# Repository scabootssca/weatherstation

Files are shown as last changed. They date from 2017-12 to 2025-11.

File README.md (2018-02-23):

Needs Src/shared/config.h made with this format:

# config.h
```
#ifndef _CONFIG_H_
#define _CONFIG_H_

#define SERVER_IP_ADDRESS "XXX.XXX.XXX.XXX"
#define SERVER_PORT 80
#define MY_IP XXX, XXX, XXX, XXX
#define GATEWAY_IP XXX, XXX, XXX, XXX
#define SUBNET_MASK XXX, XXX, XXX, XXX
#define WIFI_SSID "XXXXXXXXXXX"
#define WIFI_PASS "*******************"
#define GMT_OFFSET XX (-X or just X in hours)
#define ESP_ATMEGA_BAUD_RATE 4800

#endif
```

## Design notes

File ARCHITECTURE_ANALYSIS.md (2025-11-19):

# ATmega Weather Logger - Architecture Analysis

## Executive Summary

This document provides a comprehensive technical analysis of the ATmega Weather Logger codebase for its intended use as a budget-friendly PLC-esque automation system for greenhouses, climate automation, and gardens.

---

## 1. System Architecture Overview

### Dual-Processor Design
```
[Sensors] --> [ATmega328p] --> [SoftwareSerial @ 4800 baud] --> [ESP8266] --> [WiFi] --> [Server]
```

| Component | Role | Communication |
|---|---|---|
| ATmega328p | Main controller - sensor reading, data processing, storage | I2C, SPI, SoftwareSerial |
| ESP8266 | WiFi module - HTTP requests to server | SoftwareSerial, WiFi |

### Hardware Components

**Sensors:**
- BME280 (I2C @ 0x76) - Temperature, Humidity, Barometric Pressure
- BH1750 (I2C @ 0x23) - Lux/Light level
- DS1307 (I2C @ 0x68) - Real-time clock
- Wind vane - Analog input (ADC)
- Anemometer - Digital interrupt (pulse counting)
- Rain gauge - Digital interrupt (tipping bucket)
- Battery voltage - Analog input with voltage divider

**Peripheral ICs:**
- MCP23008 (I2C @ 0x20) - GPIO expander for ESP control
- 23A1024 (SPI) - External 1Mbit SRAM for data storage

---

## 2. Major Sections and Key Functions Analysis

### 2.1 Main Controller (`ATmega328p.ino`)

#### Initialization (`setup()`)
**Location:** Lines 328-536

**Purpose:** System initialization including watchdog, peripherals, and state restoration.

**Key Operations:**
- Enables 8-second watchdog timer
- Initializes I2C bus with timeout and recovery
- Configures SPI for external SRAM
- Sets up GPIO expander (MCP23008) for ESP control
- Configures interrupts for anemometer and rain gauge
- Restores state from external SRAM or initializes fresh
- Sends boot debug message to server

#### Main Loop (`loop()`)
**Location:** Lines 743-790

**Purpose:** Core processing loop with periodic sampling and reading generation.

**Key Operations:**
1. Pet watchdog timer
2. Handle ESP state machine
3. Take samples every 2 seconds
4. Create weather readings every 5 minutes (150 samples)
5. Trigger submission every 20 minutes (4 readings)

#### ESP State Machine (`handle_esp()`)
**Location:** Lines 539-630

**Purpose:** Manages ESP8266 lifecycle for reliable communication.

**States:**
| State | Description |
|---|---|
| `ESP_STATE_SLEEP` | ESP in deep sleep, no power consumption |
| `ESP_STATE_RESETTING` | ESP being reset, waiting for ready signals |
| `ESP_STATE_IDLE` | ESP awake and ready for commands |
| `ESP_STATE_AWAITING_RESULT` | Request sent, waiting for response |
| `ESP_STATE_AWAITING_DEBUG_RESULT` | Debug request sent |

#### Anemometer ISR (`anemometerISR()`)
**Location:** Lines 219-258

**Purpose:** Interrupt-driven wind speed measurement with debouncing.

**Key Features:**
- 50ms debounce (max ~58.4 MPH measurable)
- Accumulates time deltas for averaging
- Tracks minimum delta for gust detection
- Handles millis() rollover

#### Data Sampling (`take_sample()`)
**Location:** Lines 1182-1258

**Purpose:** Collects all sensor data and accumulates for averaging.

**Sampled Data:**
- Battery voltage (every 25th sample)
- Wind speed and direction
- Rain bucket pulses
- Temperature, pressure, humidity (BME280)
- Light level (BH1750)

### 2.2 Data Storage Module (`MCP_23A1024.h`)

#### Memory Layout
```
[0-4]     BLANK
[5-9]     populated key (0xFAD00BA6)
[10-12]   readIndex
[13-19]   BLANK
[20-22]   writeIndex
[23-31]   BLANK
[32-end]  readingAccumulator + readings circular buffer
```

**Maximum Readings:** Calculated as `(131072 - SRAM_ADDR_READINGS) / sizeof(WeatherReading)`

#### Key Functions

| Function | Purpose |
|---|---|
| `sram_init()` | Initialize SPI settings, set sequential mode |
| `sram_get_populated()` | Check/set magic key for data persistence |
| `sram_read_accumulator()` / `sram_write_accumulator()` | Persist accumulator state |
| `sram_read_reading()` / `sram_write_reading()` | Read/write from circular buffer |

### 2.3 Weather Data Module (`weather_readings.h`)

#### Data Structures

**WeatherReading** - Final averaged reading (40 bytes):
```c
struct WeatherReading {
    uint32_t timestamp;
    float temperature, humidity, pressure;
    float batteryMv, windGust, windSpeed, windDirection, lux;
    uint32_t rain;
};
```

**WeatherReadingAccumulator** - Sample accumulation (58 bytes):
```c
struct WeatherReadingAccumulator {
    uint32_t timestamp;
    int32_t temperature;
    uint32_t humidity, batteryMv, windGust, windSpeed, rain;
    uint64_t pressure, lux;
    float windDirectionX, windDirectionY;  // For vector averaging
    uint8_t numSamples, numBatterySamples;
};
```

#### Vector Wind Direction Averaging (`store_accumulator()`)
**Location:** Lines 109-166

Uses Cartesian coordinate averaging to properly handle circular mean:
```c
float avgWindX = src.windDirectionX / float(src.numSamples);
float avgWindY = src.windDirectionY / float(src.numSamples);
float angleRadians = atan(avgWindY / avgWindX);
// Quadrant correction for full 360 degrees
```

### 2.4 WiFi Module (`ESP8266.ino`)

#### Serial Protocol
**Format:** `[Command Byte][Length Byte][Data...]`

**Commands:**
| Code | Command | Action |
|---|---|---|
| 0 | PING | Echo test |
| 1 | REQUEST | Send HTTP GET |
| 2 | SLEEP | Enter deep sleep |
| 6 | IDLE | Reset result pins |

#### HTTP Communication (`send_request()`)
**Location:** Lines 294-358

- Connects to configured WiFi
- Sends HTTP GET request with weather data as URL parameters
- Parses response for "Success" keyword
- Sets GPIO pins to signal result to ATmega

---

## 3. Potential Bugs and Issues

### 3.1 Critical Bugs

#### Bug 1: Integer Overflow in Wind Speed Accumulation
**Location:** `ATmega328p.ino:1049`
```c
sampleAccumulator.windSpeed += int32_t(anemometerMph*100);
```
**Issue:** With 150 samples at high wind speeds, this can overflow. At 50 MPH average:
`150 * 50 * 100 = 750,000` (safe for int32_t, but marginal)

**Risk:** Medium - Only affects sustained high winds

#### Bug 2: Division by Zero in Wind Direction
**Location:** `weather_readings.h:138`
```c
float angleRadians = atan(avgWindY/avgWindX);
```
**Issue:** If `avgWindX == 0`, this causes undefined behavior.

**Fix Required:** Add check for `avgWindX == 0` before division.

#### Bug 3: Race Condition in Anemometer Variables
**Location:** `ATmega328p.ino:1036-1038`
```c
cli();
float averagePulseTDelta = anemometerTDeltaAccumulator / float(anemometerPulses);
anemometerPulses = 0;
anemometerTDeltaAccumulator = 0;
sei();
```
**Issue:** `anemometerTDeltaAccumulator` is `uint64_t` which requires multiple instructions to read on 8-bit AVR. While `cli()` is called, the ISR could have updated it atomically during the division if the division is optimized.

**Risk:** Low - The `cli()` prevents the issue, but code is fragile.

#### Bug 4: Buffer Overflow in ESP Serial
**Location:** `ESP8266.ino:243-246`
```c
if (ATmegaSerialIndex >= ATMEGA_BUFFER_SIZE-1) {
    Serial.println("Serial buffer overflow!");
    ATmegaSerialIndex = 0;
}
```
**Issue:** This check happens AFTER writing to the buffer, potentially allowing one byte overflow.

#### Bug 5: Uninitialized lastAnemometerPulseMillis After Reset
**Location:** `ATmega328p.ino:221-225`
```c
if (lastAnemometerPulseMillis == 0) {
    lastAnemometerPulseMillis = millis();
    return;
}
```
**Issue:** If the first pulse happens at millis() = 0 (just after reset), it will be skipped and the next tDelta will be very large.

### 3.2 Security Vulnerabilities

#### Vulnerability 1: No HTTPS - Data in Plaintext
**Location:** `ESP8266.ino:320-322`
```c
client.print(String("GET ") + url + " HTTP/1.1\r\n" + ...);
```
**Risk:** HIGH - All sensor data transmitted unencrypted
**Impact:** Data interception, potential for injection attacks

#### Vulnerability 2: Hardcoded Credentials in Config
**Location:** `config.h` (user-created)
```c
#define WIFI_PASS "*******************"
```
**Risk:** Medium - Credentials stored in plaintext
**Mitigation:** File is gitignored, but should use secure storage

#### Vulnerability 3: No Server Authentication
**Issue:** Server response is only checked for "Success" string - no verification of server identity
**Risk:** Medium - Man-in-the-middle attacks possible

#### Vulnerability 4: URL Injection Potential
**Location:** `ATmega328p.ino:814-865`
**Issue:** Sensor values are concatenated directly into URL without sanitization
**Risk:** Low - Controlled input from sensors, but no validation

### 3.3 Performance Bottlenecks

#### Bottleneck 1: String Concatenation in URL Generation
**Location:** `ATmega328p.ino:814-865`
```c
String outputUrl = "/report.php?";
outputUrl += "temp=";
outputUrl += weatherReading.temperature;
// ... repeated 15+ times
```
**Issue:** Each `+=` causes memory reallocation, fragmenting heap
**Impact:** ~300+ bytes allocated/deallocated per submission

#### Bottleneck 2: Blocking Delays in Battery Reading
**Location:** `ATmega328p.ino:1119-1141`
```c
mcp.digitalWrite(MCP_SOLAR_ENABLE_PIN, LOW);
delay(50);
mcp.digitalWrite(MCP_BAT_DIV_ENABLE_PIN, HIGH);
delay(50);
```
**Issue:** 100ms+ blocking delay during every 25th sample
**Impact:** Missed anemometer pulses during battery reading

#### Bottleneck 3: Slow SoftwareSerial Baud Rate
**Location:** `config.h`
```c
#define ESP_ATMEGA_BAUD_RATE 4800
```
**Issue:** At 4800 baud, a 200-byte URL takes ~400ms to transmit
**Impact:** Extended communication time, increased power consumption

#### Bottleneck 4: pow() Function for ADC Oversampling
**Location:** `ATmega328p.ino:731`
```c
short numSamples = (int)pow(4.0, oversampleBits);
```
**Issue:** Floating-point pow() is expensive; result is always 16 (4^2)
**Fix:** Use `(1 << (2 * oversampleBits))` or pre-computed constant

---

## 4. Code Quality Evaluation

### 4.1 Readability

**Score: 6/10**

**Strengths:**
- Consistent naming convention (snake_case for functions, camelCase for variables)
- Good use of `#define` for configuration constants
- Helpful comments explaining WMO standards compliance
- Clear separation of concerns between files

**Weaknesses:**
- Many commented-out code blocks (e.g., lines 667-707, 709-720)
- Magic numbers in some places (e.g., 50ms debounce, line 240)
- Long functions (setup() is 200+ lines)
- Inconsistent debug print formatting

### 4.2 Maintainability

**Score: 5/10**

**Strengths:**
- Modular design with separate header files
- Configuration centralized in config.h
- Debug levels (0-3) for different verbosity

**Weaknesses:**
- No unit tests
- Functions in header files (`weather_readings.h`, `MCP_23A1024.h`) - should be .cpp
- Global state makes testing difficult
- No API documentation
- Hardcoded I2C addresses scattered throughout

### 4.3 Best Practices Adherence

**Score: 6/10**

**Adherence:**
- Watchdog timer implementation
- Power management (forced mode, deep sleep)
- State persistence across resets
- Vector averaging for circular data

**Violations:**
- Functions defined in headers (not inline)
- No const correctness on function parameters
- Raw pointers without bounds checking
- No PROGMEM usage for constant strings
- Large String objects on stack

---

## 5. Improvement Recommendations

### 5.1 Critical Fixes

1. **Fix division by zero in wind direction calculation**
   ```c
   if (avgWindX == 0.0f) {
       dest->windDirection = (avgWindY >= 0) ? 90.0f : 270.0f;
   } else {
       float angleRadians = atan2(avgWindY, avgWindX); // Use atan2
       // ... rest of calculation
   }
   ```

2. **Use atan2() for wind direction** - Eliminates quadrant checking
   ```c
   float angleDegrees = atan2(avgWindY, avgWindX) * 180.0 / M_PI;
   if (angleDegrees < 0) angleDegrees += 360.0;
   ```

3. **Add atomic read for 64-bit variables**
   ```c
   cli();
   uint64_t localAccum = anemometerTDeltaAccumulator;
   unsigned int localPulses = anemometerPulses;
   anemometerPulses = 0;
   anemometerTDeltaAccumulator = 0;
   sei();
   if (localPulses > 0) {
       float averagePulseTDelta = localAccum / float(localPulses);
   }
   ```

### 5.2 Performance Optimizations

1. **Pre-allocate URL buffer**
   ```c
   char urlBuffer[300];
   snprintf(urlBuffer, sizeof(urlBuffer),
       "/report.php?temp=%.2f&hum=%.2f&pres=%.2f...",
       weatherReading.temperature, ...);
   ```

2. **Increase baud rate to 9600 or 19200**
   - SoftwareSerial can handle higher rates
   - Reduces transmission time by 50-75%

3. **Replace pow() with bit shift**
   ```c
   short numSamples = 1 << (2 * oversampleBits); // 4^n = 2^(2n)
   ```

4. **Use PROGMEM for constant strings**
   ```c
   const char URL_TEMP[] PROGMEM = "&temp=";
   ```

### 5.3 Security Improvements

1. **Implement HTTPS** using ESP8266's WiFiClientSecure
2. **Add server certificate validation**
3. **Consider MQTT** instead of HTTP for better efficiency and security
4. **Add CRC checksums** to SRAM data

### 5.4 Code Quality Improvements

1. **Refactor long functions** - Break setup() into init_sensors(), init_communication(), init_storage()
2. **Remove dead code** - Clean up commented sections
3. **Add doxygen comments** for API documentation
4. **Create proper .cpp files** for header implementations
5. **Add integration tests** using mock sensors

---

## 6. Feature Roadmap: Programmable Automation Rules

### [New Feature Name]
**Conditional Automation Engine (CAE)**

### [Summary of Feature]
A rule-based automation system that allows users to define conditional triggers and actions based on sensor readings. This transforms the weather logger into a true PLC-like controller capable of automated responses such as activating relays, controlling irrigation, or triggering alerts.

### [Justification of Feature]

**Why This Feature Is Essential for PLC/Automation:**

1. **Core PLC Functionality** - Professional PLCs (Allen-Bradley, Siemens) are defined by conditional logic: IF condition THEN action. The current system only logs data without acting on it.

2. **Greenhouse Requirements** - Automated climate control requires:
   - Temperature threshold ventilation
   - Humidity-based misting
   - Light-level shading
   - Frost protection

3. **Cost Reduction** - Eliminates need for separate cloud processing or additional controllers

4. **Offline Operation** - Rules execute locally even without WiFi connectivity

5. **Real-Time Response** - Sub-second reaction to sensor changes vs. cloud round-trip latency

**Competitive Analysis:**

| System | Local Automation | Price |
|---|---|---|
| This Project (current) | No | ~$30 |
| This Project (with CAE) | Yes | ~$35 |
| Raspberry Pi + Home Assistant | Yes | ~$60 |
| Commercial Greenhouse Controller | Yes | $200-2000 |

### [Overview of Functionality]

#### Rule Structure
```
RULE: [name]
  IF: [sensor] [operator] [threshold]
  AND/OR: [sensor] [operator] [threshold] (optional)
  THEN: [action] [parameters]
  ELSE: [action] [parameters] (optional)
  HYSTERESIS: [value] (optional)
  COOLDOWN: [seconds] (optional)
```

#### Example Rules
```
RULE: "Frost Protection"
  IF: temperature < 2.0
  THEN: relay_on(1)
  ELSE: relay_off(1)
  HYSTERESIS: 1.0

RULE: "Ventilation"
  IF: temperature > 28.0
  OR: humidity > 85.0
  THEN: relay_on(2)
  COOLDOWN: 300

RULE: "Night Lighting"
  IF: lux < 100
  AND: hour >= 6
  AND: hour <= 20
  THEN: relay_on(3)
```

#### Supported Conditions
- All sensor readings: temperature, humidity, pressure, windSpeed, windGust, windDirection, rain, lux, batteryMv
- Time-based: hour, minute, dayOfWeek
- Derived values: heatIndex, dewPoint

#### Supported Actions
- `relay_on(n)` / `relay_off(n)` - Control output relays
- `pwm_set(n, duty)` - PWM output control
- `alert(type)` - Send alert to server
- `log(message)` - Log custom message

### [Step-by-Step Implementation]

---

## Implementation Roadmap

### Phase 1: Hardware Foundation

| Step | Task | Files to Modify | Expected Outcome |
|---|---|---|---|
| 1.1 | Add relay output capability | `ATmega328p.ino`, `Schematic/WeatherStation.sch` | MCP23008 configured with output pins for 4 relays |
| 1.2 | Add EEPROM storage for rules | `ATmega328p.ino` | Functions to read/write rule data to EEPROM |
| 1.3 | Define rule data structures | `automation_rules.h` (new) | Compact structs fitting in EEPROM |

**Step 1.1 Details: Relay Output Configuration**

Modify MCP23008 initialization to add output pins:

```c
// In ATmega328p.ino setup()
#define MCP_RELAY_1_PIN 3
#define MCP_RELAY_2_PIN 4

mcp.pinMode(MCP_RELAY_1_PIN, OUTPUT);
mcp.pinMode(MCP_RELAY_2_PIN, OUTPUT);
mcp.digitalWrite(MCP_RELAY_1_PIN, LOW);
mcp.digitalWrite(MCP_RELAY_2_PIN, LOW);
```

**Step 1.2 Details: EEPROM Storage**

```c
// EEPROM layout for rules
#define EEPROM_RULES_START 0
#define EEPROM_RULES_COUNT_ADDR 0
#define EEPROM_RULES_DATA_ADDR 2
#define MAX_RULES 8
```

**Step 1.3 Details: Rule Data Structures**

Create `automation_rules.h`:

```c
#ifndef _AUTOMATION_RULES_H_
#define _AUTOMATION_RULES_H_

#include <EEPROM.h>

// Sensor types (4 bits)
enum SensorType : uint8_t {
    SENSOR_TEMPERATURE = 0,
    SENSOR_HUMIDITY = 1,
    SENSOR_PRESSURE = 2,
    SENSOR_WIND_SPEED = 3,
    SENSOR_WIND_GUST = 4,
    SENSOR_WIND_DIR = 5,
    SENSOR_RAIN = 6,
    SENSOR_LUX = 7,
    SENSOR_BATTERY = 8,
    SENSOR_HOUR = 9,
    SENSOR_MINUTE = 10,
    SENSOR_HEAT_INDEX = 11
};

// Operators (3 bits)
enum Operator : uint8_t {
    OP_LESS_THAN = 0,
    OP_GREATER_THAN = 1,
    OP_EQUALS = 2,
    OP_NOT_EQUALS = 3,
    OP_LESS_EQUAL = 4,
    OP_GREATER_EQUAL = 5
};

// Action types (4 bits)
enum ActionType : uint8_t {
    ACTION_RELAY_ON = 0,
    ACTION_RELAY_OFF = 1,
    ACTION_PWM_SET = 2,
    ACTION_ALERT = 3,
    ACTION_NONE = 15
};

// Condition structure (4 bytes)
struct Condition {
    uint8_t sensorType : 4;
    uint8_t op : 3;
    uint8_t nextLogic : 1; // 0=AND, 1=OR
    int16_t threshold; // Fixed-point: actual = threshold / 100
    uint8_t reserved;
};

// Action structure (2 bytes)
struct Action {
    uint8_t actionType : 4;
    uint8_t param1 : 4;    // relay number or PWM channel
    uint8_t param2;        // PWM duty cycle or alert type
};

// Complete rule (16 bytes for EEPROM efficiency)
struct AutomationRule {
    uint8_t enabled : 1;
    uint8_t hasElse : 1;
    uint8_t conditionCount : 2;  // 1-3 conditions
    uint8_t reserved : 4;

    Condition conditions[2];     // 8 bytes
    Action thenAction;           // 2 bytes
    Action elseAction;           // 2 bytes

    uint8_t hysteresis;          // Fixed-point / 10
    uint8_t cooldownMinutes;     // Max 255 minutes
};

#define RULE_SIZE sizeof(AutomationRule)  // 16 bytes

#endif
```

---

### Phase 2: Rule Evaluation Engine

| Step | Task | Files to Modify | Expected Outcome |
|---|---|---|---|
| 2.1 | Implement condition evaluation | `automation_engine.h` (new) | Function to evaluate single condition |
| 2.2 | Implement rule evaluation | `automation_engine.h` | Function to evaluate complete rule with AND/OR |
| 2.3 | Add hysteresis support | `automation_engine.h` | Prevent rapid on/off cycling |
| 2.4 | Add cooldown tracking | `automation_engine.h` | Rate limiting for actions |

**Step 2.1-2.4 Details: Create `automation_engine.h`**

```c
#ifndef _AUTOMATION_ENGINE_H_
#define _AUTOMATION_ENGINE_H_

#include "automation_rules.h"
#include "weather_readings.h"

// State tracking for hysteresis and cooldowns
struct RuleState {
    bool lastResult;
    uint32_t lastActionTime;
    float lastThresholdValue;
};

RuleState ruleStates[MAX_RULES];

// Get current sensor value
float getSensorValue(SensorType sensor, WeatherReading* reading) {
    switch (sensor) {
        case SENSOR_TEMPERATURE: return reading->temperature;
        case SENSOR_HUMIDITY: return reading->humidity;
        case SENSOR_PRESSURE: return reading->pressure / 100.0; // hPa
        case SENSOR_WIND_SPEED: return reading->windSpeed;
        case SENSOR_WIND_GUST: return reading->windGust;
        case SENSOR_WIND_DIR: return reading->windDirection;
        case SENSOR_RAIN: return reading->rain;
        case SENSOR_LUX: return reading->lux;
        case SENSOR_BATTERY: return reading->batteryMv;
        case SENSOR_HOUR: return RTC.now().hour();
        case SENSOR_MINUTE: return RTC.now().minute();
        case SENSOR_HEAT_INDEX:
            return computeHeatIndex(reading->temperature, reading->humidity, false);
        default: return 0;
    }
}

// Evaluate single condition
bool evaluateCondition(Condition* cond, WeatherReading* reading) {
    float value = getSensorValue((SensorType)cond->sensorType, reading);
    float threshold = cond->threshold / 100.0;

    switch ((Operator)cond->op) {
        case OP_LESS_THAN: return value < threshold;
        case OP_GREATER_THAN: return value > threshold;
        case OP_EQUALS: return abs(value - threshold) < 0.01;
        case OP_NOT_EQUALS: return abs(value - threshold) >= 0.01;
        case OP_LESS_EQUAL: return value <= threshold;
        case OP_GREATER_EQUAL: return value >= threshold;
        default: return false;
    }
}

// Evaluate complete rule with hysteresis
bool evaluateRule(AutomationRule* rule, WeatherReading* reading,
                  uint8_t ruleIndex, uint32_t currentTime) {

    // Check cooldown
    if (rule->cooldownMinutes > 0) {
        uint32_t cooldownSecs = rule->cooldownMinutes * 60;
        if (currentTime - ruleStates[ruleIndex].lastActionTime < cooldownSecs) {
            return ruleStates[ruleIndex].lastResult;
        }
    }

    // Evaluate conditions
    bool result = evaluateCondition(&rule->conditions[0], reading);

    for (int i = 1; i < rule->conditionCount && i < 2; i++) {
        bool condResult = evaluateCondition(&rule->conditions[i], reading);

        if (rule->conditions[i-1].nextLogic == 0) { // AND
            result = result && condResult;
        } else { // OR
            result = result || condResult;
        }
    }

    // Apply hysteresis
    if (rule->hysteresis > 0 && ruleStates[ruleIndex].lastResult != result) {
        float hysteresisValue = rule->hysteresis / 10.0;
        float primaryValue = getSensorValue(
            (SensorType)rule->conditions[0].sensorType, reading);
        float threshold = rule->conditions[0].threshold / 100.0;

        // Only allow state change if we've moved past hysteresis band
        if (result) {
            // Turning on - check we're sufficiently above threshold
            if (primaryValue < threshold + hysteresisValue) {
                result = ruleStates[ruleIndex].lastResult;
            }
        } else {
            // Turning off - check we're sufficiently below threshold
            if (primaryValue > threshold - hysteresisValue) {
                result = ruleStates[ruleIndex].lastResult;
            }
        }
    }

    return result;
}

// Execute action
void executeAction(Action* action) {
    switch ((ActionType)action->actionType) {
        case ACTION_RELAY_ON:
            mcp.digitalWrite(MCP_RELAY_1_PIN + action->param1, HIGH);
            Serial.print("Relay ON: ");
            Serial.println(action->param1);
            break;

        case ACTION_RELAY_OFF:
            mcp.digitalWrite(MCP_RELAY_1_PIN + action->param1, LOW);
            Serial.print("Relay OFF: ");
            Serial.println(action->param1);
            break;

        case ACTION_PWM_SET:
            // Would require additional hardware
            analogWrite(action->param1, action->param2);
            break;

        case ACTION_ALERT:
            // Queue alert for next ESP transmission
            esp_send_debug_request(String("ALERT,") + action->param1);
            break;

        case ACTION_NONE:
        default:
            break;
    }
}

// Main evaluation loop - call this after each reading
void evaluateAllRules(WeatherReading* reading, uint32_t currentTime) {
    uint8_t ruleCount = EEPROM.read(EEPROM_RULES_COUNT_ADDR);

    for (uint8_t i = 0; i < ruleCount && i < MAX_RULES; i++) {
        AutomationRule rule;
        EEPROM.get(EEPROM_RULES_DATA_ADDR + (i * RULE_SIZE), rule);

        if (!rule.enabled) continue;

        bool result = evaluateRule(&rule, reading, i, currentTime);

        // Execute action if state changed
        if (result != ruleStates[i].lastResult) {
            if (result) {
                executeAction(&rule.thenAction);
            } else if (rule.hasElse) {
                executeAction(&rule.elseAction);
            }

            ruleStates[i].lastResult = result;
            ruleStates[i].lastActionTime = currentTime;
        }
    }
}

#endif
```

---

### Phase 3: Integration and Configuration

| Step | Task | Files to Modify | Expected Outcome |
|---|---|---|---|
| 3.1 | Integrate engine into main loop | `ATmega328p.ino` | Rules evaluated after each reading |
| 3.2 | Add serial configuration interface | `ATmega328p.ino` | Commands to add/edit/delete rules |
| 3.3 | Add rule status to server reports | `ATmega328p.ino` | Report relay states and rule triggers |

**Step 3.1 Details: Main Loop Integration**

```c
// In ATmega328p.ino, after line 771 (after creating currentReading)
#include "automation_engine.h"

// After: WeatherReading currentReading = get_averaged_accumulator(sampleAccumulator);
evaluateAllRules(&currentReading, get_unixtime());
```

**Step 3.2 Details: Serial Configuration**

Add command parser for rule management:

```c
// Serial command format: !R[cmd][data]
// !RA[rule_bytes] - Add rule
// !RD[index] - Delete rule
// !RL - List rules
// !RE[index] - Enable rule
// !RX[index] - Disable rule
```

**Step 3.3 Details: Server Reporting**

Add relay states to URL:

```c
// In generate_request_url()
outputUrl += "&r1=";
outputUrl += mcp.digitalRead(MCP_RELAY_1_PIN);
outputUrl += "&r2=";
outputUrl += mcp.digitalRead(MCP_RELAY_2_PIN);
```

---

### Phase 4: Advanced Features (Optional)

| Step | Task | Files to Modify | Expected Outcome |
|---|---|---|---|
| 4.1 | Add web-based configuration | `ESP8266.ino` | HTTP endpoint for rule management |
| 4.2 | Add rule scheduling | `automation_rules.h` | Time-window restrictions for rules |
| 4.3 | Add rule chaining | `automation_engine.h` | Rules can trigger other rules |
| 4.4 | Add PID control | `pid_control.h` (new) | Proportional control for gradual adjustments |

---

## Technical Approach Alternatives

### Approach 1: EEPROM-Based Rules (Recommended)

**Description:** Store rules in ATmega328p's internal EEPROM (1KB)

**Pros:**
- No additional hardware required
- Persists across power cycles
- Fast read access
- Simple implementation

**Cons:**
- Limited to ~50-60 rules (16 bytes each)
- EEPROM has limited write cycles (100,000)
- No easy backup/restore

**Implementation Complexity:** Medium

### Approach 2: External SRAM Rules

**Description:** Store rules in existing 23A1024 SRAM alongside weather data

**Pros:**
- Much larger capacity (thousands of rules)
- Unlimited write cycles
- Already have hardware

**Cons:**
- Rules lost on power loss (unless battery-backed)
- More complex memory management
- Potential conflicts with weather data

**Implementation Complexity:** High

### Approach 3: SD Card Storage

**Description:** Add SD card module for rule storage and logging

**Pros:**
- Virtually unlimited storage
- Easy backup/restore (remove card)
- Human-readable rule files possible
- Extended data logging

**Cons:**
- Additional hardware cost (~$5)
- Higher power consumption
- More complex code (FAT filesystem)
- Slower access than EEPROM

**Implementation Complexity:** High

### Approach 4: Server-Side Rules with Local Cache

**Description:** Rules defined on server, cached locally for offline operation

**Pros:**
- Easy web-based configuration
- Unlimited rule complexity
- Version control possible
- No local storage limits

**Cons:**
- Requires server infrastructure
- Initial rules need network
- Sync complexity
- Higher latency for rule changes

**Implementation Complexity:** Very High

---

## Recommendation

**Implement Approach 1 (EEPROM-Based Rules)** for initial release with a migration path to Approach 3 (SD Card) for advanced users.

**Rationale:**
1. Matches the "budget-friendly" project goal
2. No additional hardware cost
3. Sufficient for typical greenhouse automation (5-20 rules)
4. Can add SD card support later as optional upgrade
5. EEPROM write cycle concerns mitigated by infrequent rule changes

---

## Memory Budget Analysis

| Component | RAM (bytes) | Flash (bytes) |
|---|---|---|
| Current firmware | ~1400 | ~22000 |
| Rule structures (8 rules) | 128 | 0 |
| Rule states | 96 | 0 |
| Engine code | 50 | ~2000 |
| **Total with CAE** | **~1674** | **~24000** |
| **ATmega328p capacity** | **2048** | **32768** |
| **Remaining** | **374** | **8768** |

The ATmega328p has sufficient resources for this implementation.

---

## Timeline Estimate

| Phase | Duration | Dependencies |
|---|---|---|
| Phase 1: Hardware Foundation | 1 week | None |
| Phase 2: Rule Engine | 2 weeks | Phase 1 |
| Phase 3: Integration | 1 week | Phase 2 |
| Phase 4: Advanced (optional) | 2-4 weeks | Phase 3 |
| Testing & Documentation | 1 week | Phase 3 |

**Total: 5-9 weeks** depending on optional features

---

## Conclusion

The ATmega Weather Logger provides a solid foundation for greenhouse automation. The primary gap for PLC-like functionality is the lack of conditional automation - the system collects data but cannot act on it autonomously.

Implementing the Conditional Automation Engine (CAE) would transform this from a passive data logger into an active controller capable of:
- Automated ventilation control
- Irrigation scheduling
- Frost protection
- Light supplementation
- Alert generation

The recommended EEPROM-based approach provides this functionality with zero additional hardware cost while leaving room for future expansion.

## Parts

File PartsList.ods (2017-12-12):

Weather Station Parts List
Price | Qty | Description
$6.99 | 1 | Jbtek BMP180 Barometric Sensor
$8.79 | 1 | HiLetgo NodeMCU ESP8266
$7.39 | 1 | DHT22
$0.01 | 1 | Red Led
$0.01 | 1 | Green Led
$0.01 | 1 | Yellow Led
$0.01 | 3 | 220K Resistor
$1.40 | 1 | TP4056 Lithium Charge Controller
$7.00 | 1 | 2.5W 5V/500mAh Solar Panel
$1.20 | 1 | 18650 Battery Holder
$8.00 | 1 | 1NCR18650B Panasonic Battery 3400mAh
$3.96 | 1 | Spray Paint (White)
$44.77 |  | Total

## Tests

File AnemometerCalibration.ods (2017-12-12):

 | Anemometer Calibration Data
MPH | 5 | 10 | 15 | 20 | 25 | 30 | 35 | 40 | 45
Standard Deviation | 19.2787094758247 | 15.9263931886664 | 13.05170252402 | 10.0660540325881 | 11.0554159678513 | 21.2593316845443 | 15.3785564992297 | 19.7686620690425 | 17.4122801493659 |  | 5 MPH
Mean | 61.1538461538462 | 84.5 | 156.285714285714 | 195.461538461538 | 249 | 304.428571428571 | 369 | 417 | 470.75
RPM per MPH | 12.2307692307692 | 8.45 | 10.4190476190476 | 9.7730769230769 | 9.96 | 10.147619047619 | 10.5428571428571 | 10.425 | 10.4611111111111 |  | Varience Per Sample
Datapoints (RPM) | 57 | 57 | 172 | 198 | 256 | 300 | 352 | 405 | 483 |  | 17.2544378698229
 | 94 | 91 | 172 | 204 | 243 | 329 | 365 | 410 | 441 |  | 1078.8698224852
 | 78 | 108 | 163 | 182 | 256 | 329 | 365 | 416 | 476 |  | 283.792899408282
 | 54 | 92 | 146 | 197 | 270 | 309 | 394 | 422 | 483 |  | 51.1775147929001
 | 31 | 95 | 152 | 200 | 240 | 272 |  | 447 |  |  | 909.254437869826
 | 51 | 90 | 150 | 182 | 250 | 315 |  | 416 |  |  | 103.100591715977
 | 60 | 85 | 142 | 201 | 236 | 277 |  | 416 |  |  | 1.33136094674568
 | 84 | 83 | 148 | 208 | 234 |  |  | 434 |  |  | 521.946745562128
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

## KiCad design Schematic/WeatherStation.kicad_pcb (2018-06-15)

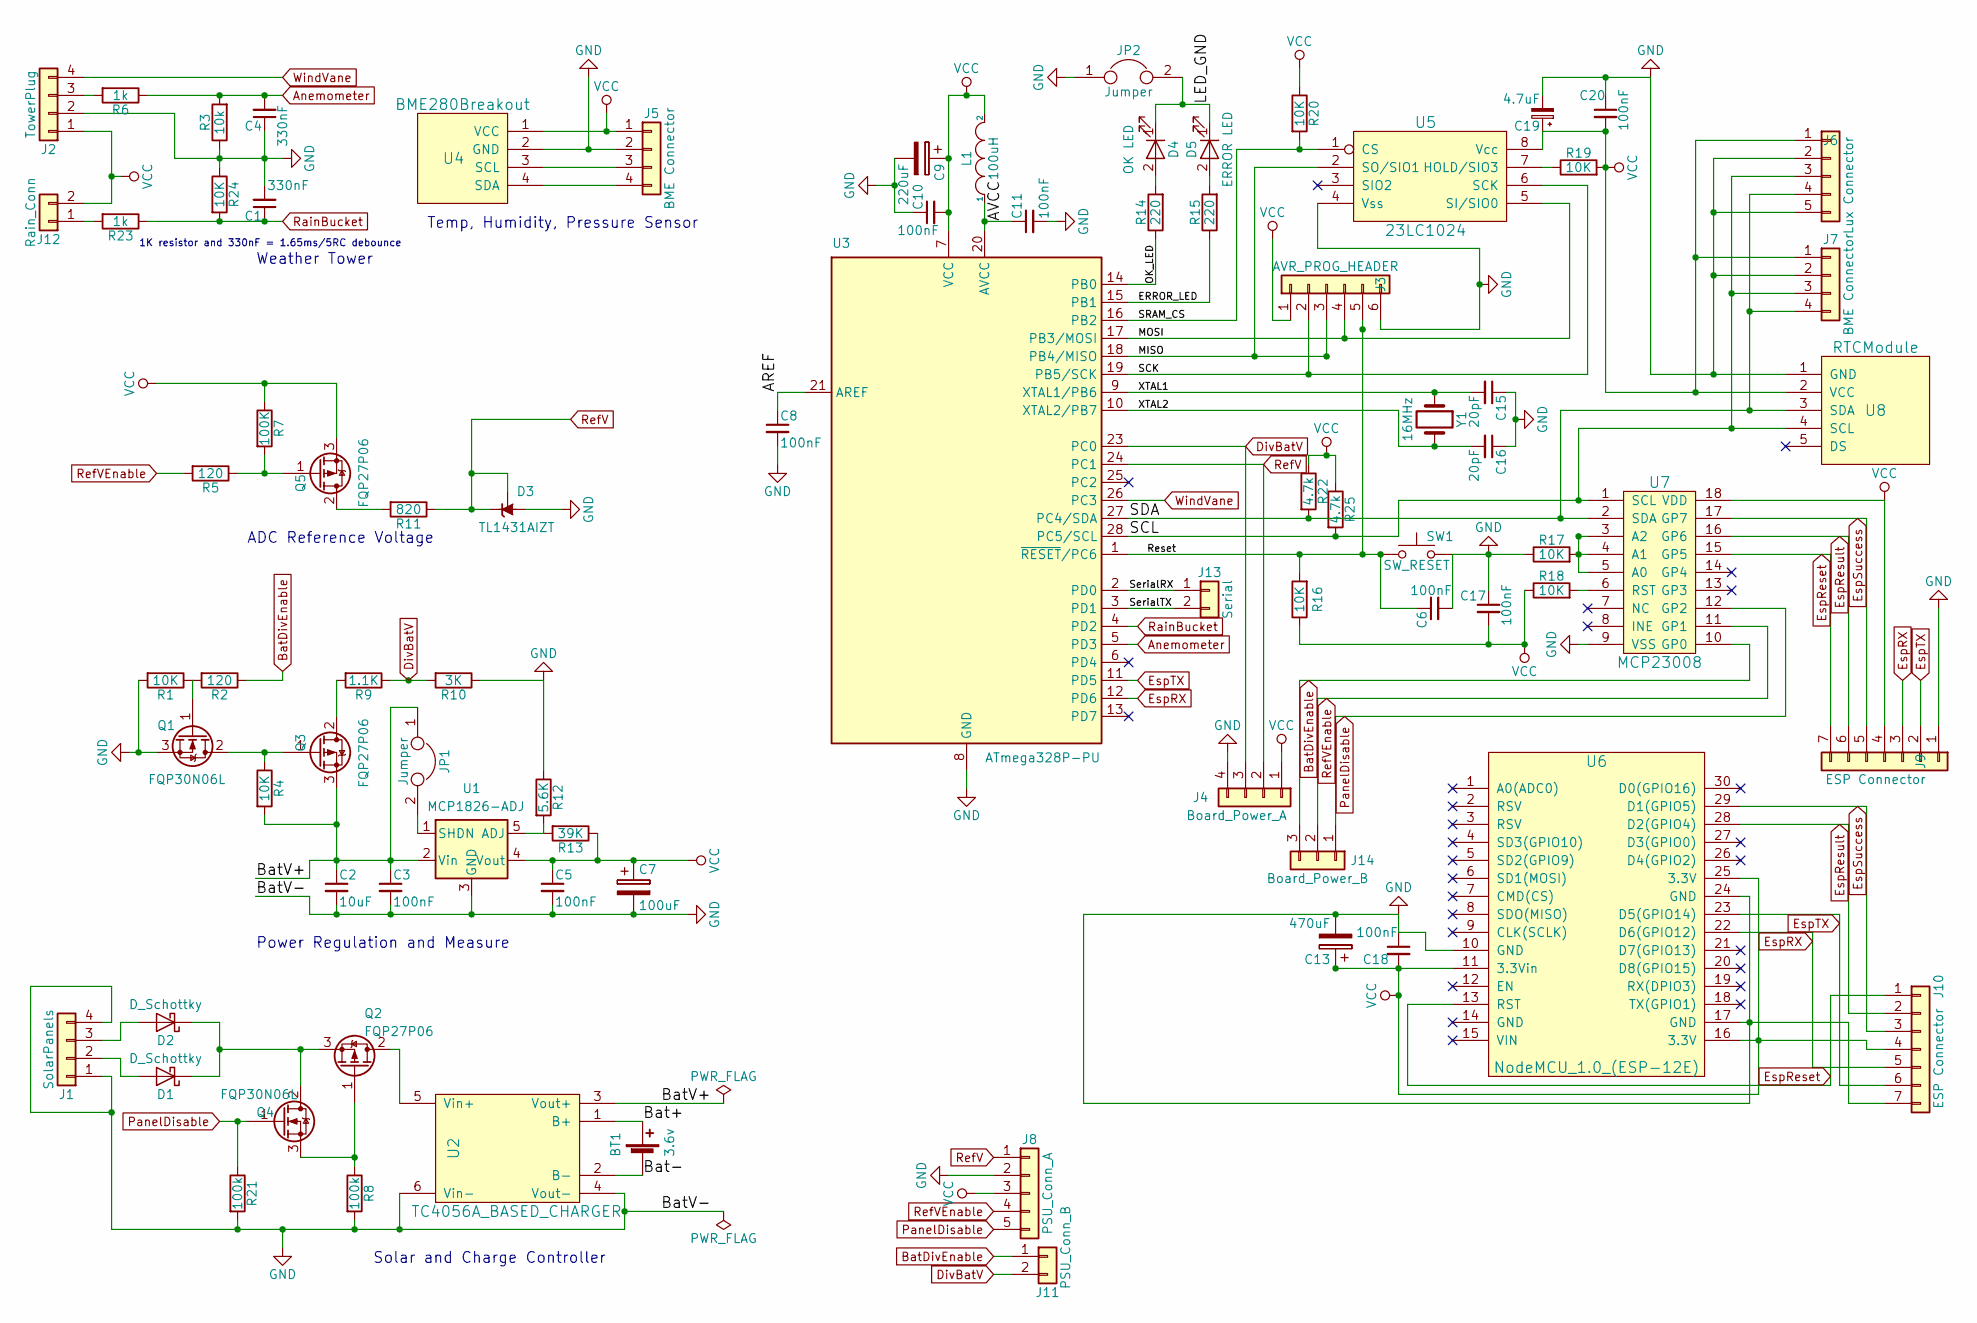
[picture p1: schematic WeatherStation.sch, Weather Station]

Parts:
BT1: 3.6v; Keystone_1042_1x18650
C1, C4: 330nF; CP_Radial_D5.0mm_P2.50mm
C2: 10uF; C_Disc_D5.1mm_W3.2mm_P5.00mm
C3, C5, C6, C8, C10, C11, C17, C18, C20: 100nF; C_Disc_D5.0mm_W2.5mm_P5.00mm
C7: 100uF; CP_Radial_D5.0mm_P2.50mm
C9: 220uF; CP_Radial_D6.3mm_P2.50mm
C13: 470uF; CP_Radial_D8.0mm_P2.50mm
C15, C16: 20pF; C_Disc_D5.0mm_W2.5mm_P5.00mm
C19: 4.7uF; CP_Radial_D4.0mm_P2.00mm
D1, D2: D_Schottky; D_DO-15_P12.70mm_Horizontal
D3: TL1431AIZT; TO-92_Inline_Wide
D4: OK LED; LED_D5.0mm
D5: ERROR LED; LED_D5.0mm
J1: SolarPanels; JST_XH_B04B-XH-A_04x2.50mm_Straight
J2: TowerPlug; JST_XH_B04B-XH-A_04x2.50mm_Straight
J3: AVR_PROG_HEADER; Pin_Header_Straight_1x06_Pitch2.54mm
J4: Board_Power_A; JST_XH_B04B-XH-A_04x2.54mm_Straight
J5, J7: BME Connector; JST_XH_B04B-XH-A_04x2.50mm_Straight
J6: Lux Connector; JST_XH_B04B-XH-A_04x2.50mm_Straight
J8: PSU_Conn_A; JST_XH_B05B-XH-A_05x2.50mm_Straight
J9, J10: ESP Connector; JST_XH_B06B-XH-A_07x2.50mm_Straight
J11: PSU_Conn_B; JST_XH_B02B-XH-A_02x2.50mm_Straight
J12: Rain_Conn; JST_XH_B02B-XH-A_02x2.50mm_Straight
J13: Serial; Pin_Header_Straight_1x02_Pitch2.54mm
J14: Board_Power_B; JST_XH_B03B-XH-A_03x2.50mm_Straight
JP1, JP2: Jumper; Pin_Header_Straight_1x02_Pitch2.54mm
L1: 100uH; L_Axial_L5.3mm_D2.2mm_P7.62mm_Horizontal_Vishay_IM-1
Q1, Q4: FQP30N06L; TO-220-3_Vertical
Q2, Q3, Q5: FQP27P06; TO-220-3_Vertical
R1, R4, R16, R17, R18, R19, R20, R24: 10K; R_Axial_DIN0207_L6.3mm_D2.5mm_P7.62mm_Horizontal
R2, R5: 120; R_Axial_DIN0207_L6.3mm_D2.5mm_P7.62mm_Horizontal
R3: 10k; R_Axial_DIN0207_L6.3mm_D2.5mm_P7.62mm_Horizontal
R6, R23: 1k; R_Axial_DIN0207_L6.3mm_D2.5mm_P7.62mm_Horizontal
R7: 100K; R_Axial_DIN0207_L6.3mm_D2.5mm_P7.62mm_Horizontal
R8: 100k; R_Axial_DIN0204_L3.6mm_D1.6mm_P7.62mm_Horizontal
R9: 1.1K; R_Axial_DIN0207_L6.3mm_D2.5mm_P7.62mm_Horizontal
R10: 3K; R_Axial_DIN0207_L6.3mm_D2.5mm_P7.62mm_Horizontal
R11: 820; R_Axial_DIN0207_L6.3mm_D2.5mm_P7.62mm_Horizontal
R12: 5.6K; R_Axial_DIN0207_L6.3mm_D2.5mm_P7.62mm_Horizontal
R13: 39K; R_Axial_DIN0207_L6.3mm_D2.5mm_P7.62mm_Horizontal
R14, R15: 220; R_Axial_DIN0207_L6.3mm_D2.5mm_P7.62mm_Horizontal
R21: 100k; R_Axial_DIN0207_L6.3mm_D2.5mm_P7.62mm_Horizontal
R22, R25: 4.7k; R_Axial_DIN0207_L6.3mm_D2.5mm_P7.62mm_Horizontal
SW1: SW_RESET; SW_PUSH_6mm
U1: MCP1826-ADJ; TO-247-5_Vertical
U2: TC4056A_BASED_CHARGER; TC4056_BREAKOUT
U3: ATmega328P-PU; DIP-28_W7.62mm_Socket
U4: BME280Breakout; Pin_Header_Straight_1x04_Pitch2.54mm
U5: 23LC1024; DIP-8_W7.62mm_Socket
U6: NodeMCU_1.0_(ESP-12E); ESP8266_NODEMCU
U7: MCP23008; DIP-18_W7.62mm
U8: RTCModule; Pin_Header_Straight_1x05_Pitch2.54mm
Y1: 16MHz; Crystal_HC52-8mm_Vertical

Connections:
/AREF: C8.1, U3.21 (AREF)
/AVCC: C11.1, L1.1, U3.20 (AVCC)
/Bat+: BT1.1 (+), U2.1 (B+)
/Bat-: BT1.2 (-), U2.2 (B-)
/BatV+: C2.1, C3.1, JP1.1, Q3.3 (S), R4.2, U1.2 (Vin), U2.3 (Vout+)
/ERROR_LED: R15.1, U3.15 (PB1)
/LED_GND: D4.1 (K), D5.1 (K), JP2.2
/MISO: J3.3, U3.18 (PB4/MISO), U5.2 (SO/SIO1)
/MOSI: J3.4, U3.17 (PB3/MOSI), U5.5 (SI/SIO0)
/OK_LED: R14.1, U3.14 (PB0)
/Reset: C6.1, J3.5, R16.2, SW1.1, U3.1 (~RESET~/PC6)
/SCK: J3.2, U3.19 (PB5/SCK), U5.6 (SCK)
/SCL: J6.3, J7.3, R25.2, U3.28 (PC5/SCL), U7.1 (SCL), U8.4 (SCL)
/SDA: J6.4, J7.4, R22.2, U3.27 (PC4/SDA), U7.2 (SDA), U8.3 (SDA)
/SRAM_CS: R20.2, U3.16 (PB2), U5.1 (CS)
/SerialRX: J13.1, U3.2 (PD0)
/SerialTX: J13.2, U3.3 (PD1)
/XTAL1: C15.2, U3.9 (XTAL1/PB6), Y1.1
/XTAL2: C16.2, U3.10 (XTAL2/PB7), Y1.2
Anemometer: C4.2, R3.2, R6.1, U3.5 (PD3)
BatDivEnable: J11.1, J14.3, R2.1, U7.10 (GP0)
DivBatV: J4.3, J11.2, R9.1, R10.2, U3.23 (PC0)
EspRX: J9.3, J10.5, U3.12 (PD6), U6.22 (D6(GPIO12))
EspReset: J9.7, J10.1, U6.13 (RST), U7.15 (GP5)
EspResult: J9.6, J10.2, U6.28 (D2(GPIO4)), U7.16 (GP6)
EspSuccess: J9.5, J10.3, U6.29 (D1(GPIO5)), U7.17 (GP7)
EspTX: J9.2, J10.6, U3.11 (PD5), U6.23 (D5(GPIO14))
GND: C1.2, C2.2, C3.2, C4.1, C5.2, C6.2, C7.2, C8.2, C9.2, C10.1, C11.2, C13.2, C15.1, C16.1, C17.1, C18.1, C19.2, C20.1, D3.2 (A), J1.1, J1.4, J2.2, J3.6, J4.4, J5.2, J6.2, J6.5, J7.2, J8.2, J9.1, J10.7, JP2.1, Q1.3 (S), R1.2, R3.1, R8.2, R10.1, R12.1, R17.1, R21.2, R24.1, SW1.2, U1.3 (GND), U2.4 (Vout-), U2.6 (Vin-), U3.8 (GND), U3.22 (GND), U4.2 (GND), U5.4 (Vss), U6.10 (GND), U6.17 (GND), U6.24 (GND), U7.9 (VSS), U8.1 (GND)
unnamed: D1.1 (K), D2.1 (K), Q2.3 (S), Q4.2 (D)
unnamed: D1.2 (A), J1.2
unnamed: D2.2 (A), J1.3
unnamed: D4.2 (A), R14.2
unnamed: D5.2 (A), R15.2
unnamed: J2.3, R6.2
unnamed: J5.3, U4.3 (SCL)
unnamed: J5.4, U4.4 (SDA)
unnamed: J12.1, R23.2
unnamed: JP1.2, U1.1 (SHDN)
unnamed: Q1.1 (G), R1.1, R2.2
unnamed: Q1.2 (D), Q3.1 (G), R4.1
unnamed: Q2.1 (G), Q4.3 (S), R8.1
unnamed: Q2.2 (D), U2.5 (Vin+)
unnamed: Q3.2 (D), R9.2
unnamed: Q5.1 (G), R5.1, R7.2
unnamed: Q5.2 (D), R11.2
unnamed: R12.2, R13.2, U1.5 (ADJ)
unnamed: R17.2, U7.3 (A2), U7.4 (A1), U7.5 (A0)
unnamed: R18.2, U7.6 (RST)
unnamed: R19.1, U5.7 (HOLD/SIO3)
PanelDisable: J8.5, J14.1, Q4.1 (G), R21.1, U7.12 (GP2)
RainBucket: C1.1, R23.1, R24.2, U3.4 (PD2)
RefV: D3.1 (REF), D3.3 (K), J4.2, J8.1, R11.1, U3.24 (PC1)
RefVEnable: J8.4, J14.2, R5.2, U7.11 (GP1)
VCC: C5.1, C7.1, C9.1, C10.2, C13.1, C17.2, C18.2, C19.1, C20.2, J2.1, J3.1, J4.1, J5.1, J6.1, J7.1, J8.3, J9.4, J10.4, J12.2, L1.2, Q5.3 (S), R7.1, R13.1, R16.1, R18.1, R19.2, R20.1, R22.1, R25.1, U1.4 (Vout), U3.7 (VCC), U4.1 (VCC), U5.8 (Vcc), U6.11 (3.3Vin), U6.16 (3.3V), U6.25 (3.3V), U7.18 (VDD), U8.2 (VCC)
WindVane: J2.4, U3.26 (PC3)

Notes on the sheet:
Power Regulation and Measure
ADC Reference Voltage
Solar and Charge Controller
Weather Tower
Temp, Humidity, Pressure Sensor
1K resistor and 330nF = 1.65ms/5RC debounce

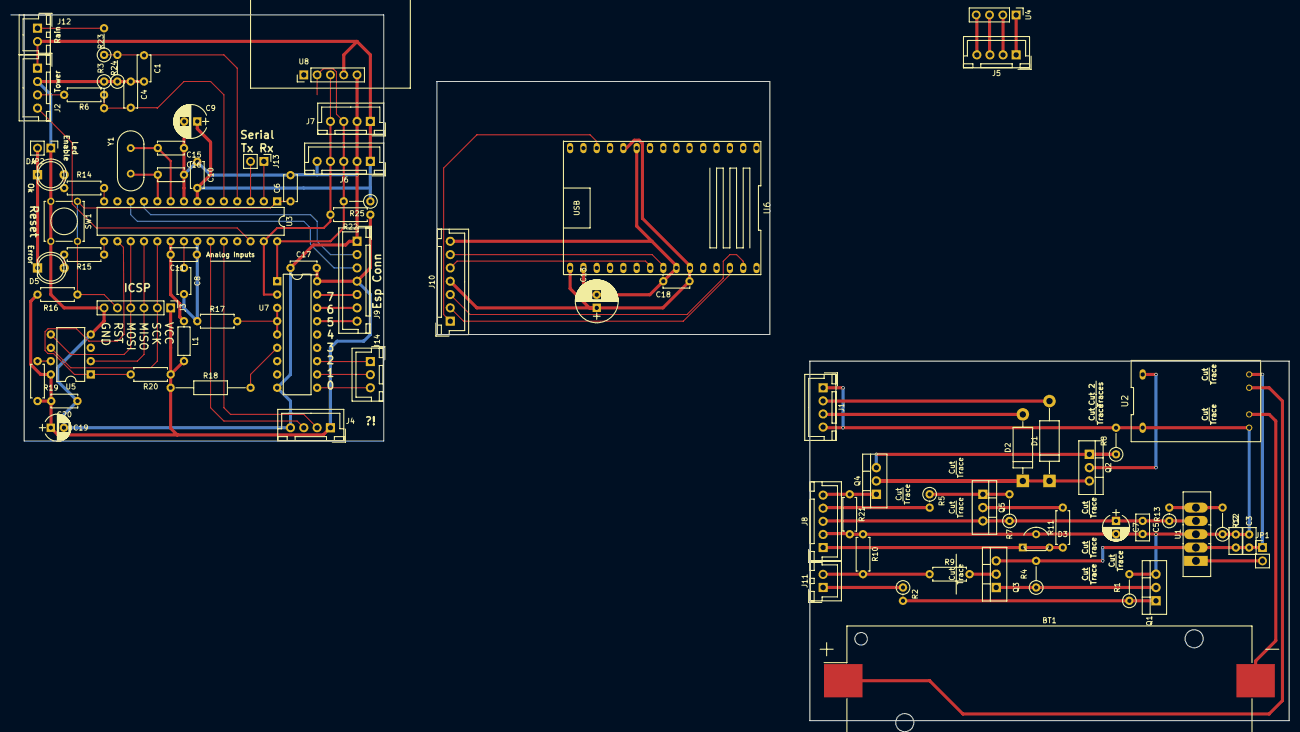
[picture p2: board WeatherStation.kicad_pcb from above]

Board: 2 copper layers, 243.8 x 134.6 mm, 81 parts (0 on the bottom side), 55 nets.

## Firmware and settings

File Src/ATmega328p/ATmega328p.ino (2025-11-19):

/*
Copyright 2017 Jason Ryan Richards

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
You should have received a copy of the GNU General Public License
along with this program.  If not, see <http://www.gnu.org/licenses/>.
*/

/*
SAMPLES:
  * 3 Second: Wind Speed, Wind Direction
  * 10 Second: Temperature, Humidity, Pressure, Global Radiation

READINGS:
  * 1 Min Avg: Temperature, Humidity, Pressure, Global Radiation
  * 2-10 Min Avg: Wind Direction, Wind Speed

Uses 13.65 ma with esp off
82.2 ma with esp on
means 68.55 ma for esp

*/
#include <avr/wdt.h>
#include "git-version.h"

#ifndef GIT_VERSION
#define GIT_VERSION 0.1
#endif

#define WD_TIMEOUT WDTO_8S
#define I2C_TIMEOUT_MS 2000
#define VERSION "v0.1"

#define CLEAN_START 0 // This will mark SRAM as unpopulated and update rtc to compile time
#define UPLOAD_TIME_OFFSET 0//53

#define SPI_HZ 500000 // 500Khz

// How many times to try to read from the sram chip before skipping
// (Will fail with programmer plugged in)
#define SRAM_MAX_READ_ATTEMPTS 2

// New timing defines
#define SAMPLE_DELTA_SHORT 3000
#define SAMPLE_DELTA_LONG 10000

// Sample and Reading defines
#define SAMPLE_INTERVAL 2000
#define READING_INTERVAL 300000 //SAMPLE_INTERVAL*5///300000 // 300000 = 5 minutes
#define SAMPLES_PER_READING READING_INTERVAL/SAMPLE_INTERVAL
#define BATTERY_SAMPLE_MODULO 25

#define READINGS_BEFORE_SUBMIT 4 // 4 == every 20 mins
#define MAX_FAILED_SUBMITS 3 // How many attempts to make with a request before waiting a few readings with a timeout
//#define SUBMIT_TIMEOUT_AFTER_FAIL 4 // How many readings to wait before before attempting to submit again after a fail

// ESP DEFINES
// All in seconds
#define ESP_RESET_READY_DELAY 5 // In seconds how long to wait after resetting the esp before it should respond
#define ESP_RESET_TIMEOUT 30 // How long after resetting to wait for the esp to pull pins low before resetting it again
#define ESP_REQUEST_TIMEOUT 60 // In seconds after sending a request to call it failed if no reply
// This will also act as a request rate limiter
// Will avoid race conditions with submissions and the esp not setting the pins
#define ESP_REQUEST_DELAY 1

// Max message size to store from serial connection with esp (BYTES)
#define ESP_RECV_BUFFER_SIZE 16

#define ESP_STATE_SLEEP 0
#define ESP_STATE_IDLE 1
#define ESP_STATE_AWAITING_RESULT 2
#define ESP_STATE_RESETTING 3
#define ESP_STATE_AWAITING_DEBUG_RESULT 4

// CALIBRATION DEFINES
// Wind Vane Calibration
#define WIND_VANE_MIN 0
#define WIND_VANE_MAX 1023

// Lux Calibration (Seems our dome blocks about 6.25% of light based off one uncontrolled rough test)
#define LUX_DOME_BLOCKING_COEF 1.0625

// Anemometer Calibration (Linear Association)
// rpm/coef = wind speed in mph
#define ANEMOMETER_CALIBRATION_COEF 0.09739260404185239 // 10.2677201193868 = revolutions per 1mph
#define ANEMOMETER_TDELTA_1_MPH 2921.778121255 // (60/10.2677201193868)*0.5 = Tdelta in samples per 1mph (For millis) 2 samples per revolution

// I2c Addresses
//0x68 == RTC
//0x76 == BME280
//0x20 == MCP23008
//0x23 == BH1730 Lux

// Pins
// Port B
#define OK_LED_PIN 8     // PB0
#define ERROR_LED_PIN 9  // PB1
#define SRAM_CS_PIN 10   // PB2
#define MOSI_PIN 11      // PB3
#define MISO_PIN 12      // PB4
#define SCK_PIN 13       // PB5

// Port C
#define BAT_ADC_PIN A0       // PC0
#define REF_ADC_PIN A1       // PC1
#define WIND_VANE_ADC_PIN A3 // PC2
// PC3
#define I2C_SDA_PIN A4       // PC4
#define I2C_SCL_PIN A5       // PC5

// Port D
#define RAIN_BUCKET_PIN 2    // PD2
#define ANEMOMETER_PIN 3     // PD3
#define DEBUG_PIN 4          // PD4
#define ESP_TX_PIN 5         // PD5
#define ESP_RX_PIN 6         // PD6


// Mcp23008 pins
#define MCP_BAT_DIV_ENABLE_PIN 0 // Biased Low Off, Pull High To Enable
#define MCP_REFV_ENABLE_PIN 1    // Biased High Off, Pull Low To Enable
#define MCP_SOLAR_ENABLE_PIN 2   // Biased High On, Pull Low To Disable
// 3
// 4
#define MCP_ESP_RESET_PIN 5
#define MCP_ESP_RESULT_PIN 6
#define MCP_ESP_SUCCESS_PIN 7

// Includes
#include <limits.h>

#include "I2C.h"
#include <SPI.h>
#include <SoftwareSerial.h>
// #include <math.h>

#include "config.h"
#include "helpers.h"
#include "weather_readings.h"

#include "RTClib.h"
#include "BME280.h"
#include "MCP_23A1024.h"
#include "Adafruit_MCP23008.h"
#include "BH1750.h"
#include "automation_engine.h"

// Globals
uint32_t bootTime;

bool debugMode = false;

bool bmeConnected = false;
bool luxConnected = false;

unsigned long lastSampleMillis = 0;

volatile unsigned long lastAnemometerPulseMillis = 0;
volatile unsigned int anemometerPulses = 0;
volatile uint64_t anemometerTDeltaAccumulator = 0;
volatile unsigned long anemometerMinTDelta = ULONG_MAX;

volatile unsigned int rainBucketPulses = 0;
unsigned long lastRainBucketReadingMillis = 0;

WeatherReadingAccumulator sampleAccumulator;

uint16_t weatherReadingWriteIndex = 0;
uint16_t weatherReadingReadIndex = 0;

//////////////////////////
// Esp interface vars   //
//////////////////////////
unsigned short espState = ESP_STATE_SLEEP;

uint32_t espResetTime = 0;
uint32_t espRequestTime = 0;

// How many failures we've had this submission attempt
unsigned int failedSubmits = 0;
// How many readings left before submitting
int submitCountdown = READINGS_BEFORE_SUBMIT;

#define REQ_FAIL_NONE 0
#define REQ_FAIL_ESP_REQUEST_TIMEOUT 1
#define REQ_FAIL_ESP_RESET_TIMEOUT 2
#define REQ_FAIL_MAX_SUBMITS 3
#define REQ_FAIL_ESP_REQUEST_FAIL 4

uint8_t requestFailReason = REQ_FAIL_NONE;

// Structures/Classes
Adafruit_MCP23008 mcp; // IO Expander
RTC_DS1307 RTC; // Real Time Clock
Adafruit_BME280 bmeSensor; // Termometer, Hygrometer, Barometer
BH1750 luxMeter; // Lux

SoftwareSerial ESPSerial(ESP_RX_PIN, ESP_TX_PIN);

char ESPRecvBuffer[ESP_RECV_BUFFER_SIZE];
short ESPRecvIndex = 0;
// bool ESPNewline = true;
// char ESPReplyBuffer[11]; // 1 + 4 + 1 + 4 + 1 == (~ Int1 ! Int2 \n)
// short ESPReplyBufferIndex = 0;
// bool ESPReplyBuffering = false;

// void anemometerISR() {
//   anemometerPulses++;
// }

void anemometerISR() {
  // If we've no pulses prior then count this and return
  if (lastAnemometerPulseMillis == 0) {
    //Serial.print("First: ");
    //Serial.println(millis());    lastAnemometerPulseMillis = millis();
    lastAnemometerPulseMillis = millis();
    return;
  }

  unsigned long tDelta = 0;

  // We rolled over
  if (millis() < lastAnemometerPulseMillis) {
    tDelta = (ULONG_MAX-lastAnemometerPulseMillis)+millis();
  } else {
    // Get the tdelta and use it to store the average
    tDelta = millis()-lastAnemometerPulseMillis;
  }

  // 50ms debounce
  // Means ~58.4 MPH is the highest we can measure with this
  if (tDelta < 50) {
    return;
  }

  //Serial.print("tDelta: ");
  //Serial.println(tDelta);

  // Add the delta to the accumulator
  anemometerTDeltaAccumulator += tDelta;

  // For peak instant gust
  if (tDelta < anemometerMinTDelta) {
    anemometerMinTDelta = tDelta;
  }

  // Save this time
  lastAnemometerPulseMillis = millis();
  anemometerPulses++;
}

void rainBucketISR() {
  rainBucketPulses++;
}

void init_bme() {
  DEBUG_PRINTLN("Init BME");

  // BME280
  bmeConnected = bmeSensor.begin(0x76);

  // Then set it to forced so it sleeps between readings
  if (bmeConnected) {
    bmeSensor.setSampling(
      bmeSensor.MODE_FORCED,
      bmeSensor.SAMPLING_X16,
      bmeSensor.SAMPLING_X16,
      bmeSensor.SAMPLING_X16,
      bmeSensor.FILTER_OFF,
      bmeSensor.STANDBY_MS_0_5
    );
  } else {
    DEBUG_PRINTLN("BME280 @ 0x76 not found.");
  }
}

bool init_i2c() {
  I2c.end();

  // Both to input to check their status
  pinMode(I2C_SDA_PIN, INPUT);
  pinMode(I2C_SCL_PIN, INPUT);

  Serial.print("Reseting I2C - SDA: ");
  Serial.print(digitalRead(I2C_SDA_PIN));
  Serial.print(" SCL: ");
  Serial.print(digitalRead(I2C_SCL_PIN));
  Serial.println();

  // Hold sda low while we pulse the clock
  pinMode(I2C_SDA_PIN, OUTPUT);
  digitalWrite(I2C_SDA_PIN, LOW);

  // Reset I2c Bus with 16 clock pulses as per specs
  pinMode(I2C_SCL_PIN, OUTPUT);

  for (int i=0; i<16; i++) {
    digitalWrite(I2C_SCL_PIN, i?HIGH:LOW);
    delay(1);
  }

  // Then a stop by raising scl then sda
  pinMode(I2C_SCL_PIN, INPUT);
  pinMode(I2C_SDA_PIN, INPUT);

  // See if its good
  // If either is low then it may still be stuck
  if (!digitalRead(I2C_SCL_PIN) || !digitalRead(I2C_SDA_PIN)) {
    esp_send_debug_request("I2C_Stuck");
    return false;
  }

  I2c.begin();
  I2c.timeOut(I2C_TIMEOUT_MS);

  Serial.println("Reset I2C");
  return true;
}

void setup() {
  // Read and reset the mcu status register
  uint8_t mcusrBootValue = MCUSR;
  MCUSR &= ~(0b00001111);

  // Enable watchdog
  wdt_enable(WD_TIMEOUT);

  // Serial
  Serial.begin(19200);
  Serial.setTimeout(500);

  DEBUG_PRINT(F("\n\nInitilizing "));
  DEBUG_PRINT(GIT_VERSION);
  DEBUG_PRINTLN(F(VERSION));
  DEBUG_PRINT("Compiled: ");
  DEBUG_PRINTLN(__DATE__);

  // We need to have something to send debug info with the esp to the server
  // ATmega328 Datasheet Section 15.9.1 (MCU Status Register)
  DEBUG_PRINTLN(F("MCUSR Value: "));
  DEBUG_PRINT(F("WDRF: "));
  DEBUG_PRINTLN((mcusrBootValue>>WDRF)&1);
  DEBUG_PRINT(F("BORF: "));
  DEBUG_PRINTLN((mcusrBootValue>>BORF)&1);
  DEBUG_PRINT(F("EXTRF: "));
  DEBUG_PRINTLN((mcusrBootValue>>EXTRF)&1);
  DEBUG_PRINT(F("PORF: "));
  DEBUG_PRINTLN((mcusrBootValue>>PORF)&1);

  // Set reference voltage pin proper
  //Bits 7:6 – REFSn: Reference Selection [n = 1:0]
  // 01 = AV CC with external capacitor at AREF pin
  //DEBUG_PRINT("Setting ADMUX: ");
  analogReference(DEFAULT);
  //ADMUX |= 0b01000000;
  Serial.print("ADMUX: ");
  Serial.println(ADMUX, BIN);

  // Esp serial
  ESPSerial.begin(ESP_ATMEGA_BAUD_RATE);
  ESPSerial.setTimeout(500);

  DEBUG_PRINTLN("1."); // Esp Serial DONE

  // Indicator LEDS
  pinMode(OK_LED_PIN, OUTPUT);
  pinMode(ERROR_LED_PIN, OUTPUT);
  digitalWrite(OK_LED_PIN, HIGH);
  digitalWrite(ERROR_LED_PIN, HIGH);

  // Battery pins
  pinMode(BAT_ADC_PIN, INPUT);

  DEBUG_PRINTLN("2."); // ATmega pins DONE

  // Inter-Chip interfaces
  init_i2c();

  SPI.begin();
  //TWBR = 72;  // 50 kHz at 8 MHz clock

  DEBUG_PRINTLN("3."); // Interfaces started DONE

  // mcp23008 begin
  mcp.begin();      // use default address 0

  mcp.pinMode(MCP_ESP_RESET_PIN, INPUT); // Input while were not using it to not interfere with ESP programming
  mcp.pinMode(MCP_ESP_RESULT_PIN, INPUT);
  mcp.pinMode(MCP_ESP_SUCCESS_PIN, INPUT);

  // Solar panel control pin
  mcp.pinMode(MCP_SOLAR_ENABLE_PIN, OUTPUT);
  mcp.digitalWrite(MCP_SOLAR_ENABLE_PIN, HIGH);

  mcp.pinMode(MCP_REFV_ENABLE_PIN, OUTPUT);
  mcp.digitalWrite(MCP_REFV_ENABLE_PIN, HIGH);
  //mcp.digitalWrite(MCP_REFV_ENABLE_PIN, LOW);

  mcp.pinMode(MCP_BAT_DIV_ENABLE_PIN, OUTPUT);
  mcp.digitalWrite(MCP_BAT_DIV_ENABLE_PIN, LOW);
  //mcp.digitalWrite(MCP_BAT_DIV_ENABLE_PIN, HIGH);

  DEBUG_PRINTLN("4."); // MCP pins set DONE

  // Debug pin
  pinMode(DEBUG_PIN, INPUT);
  debugMode = digitalRead(DEBUG_PIN);

  // Interrupts
  pinMode(ANEMOMETER_PIN, INPUT);
  digitalWrite(ANEMOMETER_PIN, LOW);
  attachInterrupt(digitalPinToInterrupt(ANEMOMETER_PIN), anemometerISR, RISING);

  pinMode(RAIN_BUCKET_PIN, INPUT);
  digitalWrite(RAIN_BUCKET_PIN, LOW);
  attachInterrupt(digitalPinToInterrupt(RAIN_BUCKET_PIN), rainBucketISR, RISING);
  sei();

  // Wind vane
  pinMode(WIND_VANE_ADC_PIN, INPUT);

  DEBUG_PRINTLN("5."); // Interrupts DONE

  // Clock
  RTC.begin();

  DEBUG_PRINTLN("6."); // RTC DONE

  // Lux Sensor (BH1750)
  luxMeter.begin(BH1750_ONE_TIME_HIGH_RES_MODE); // One shot then sleep
  luxConnected = true;

  DEBUG_PRINTLN("7"); // Lux meter DONE

  // Check to see if the RTC is keeping time.  If it is, load the time from your computer.
  if (CLEAN_START || !RTC.isrunning()) {
    // This will reflect the time that your sketch was compiled
    // Sucks cause if it takes forever to upload then its funny
    DEBUG_PRINTLN(F("Syncing RTC to compile time (local))"));
    RTC.adjust(DateTime(DateTime(__DATE__, __TIME__) - TimeSpan(60*60*GMT_OFFSET) + TimeSpan(UPLOAD_TIME_OFFSET)));
  }

  // Store boot time
  bootTime = RTC.now().unixtime();
  Serial.print("Boot Time: ");
  print_pretty_timestamp(bootTime);
  Serial.println();

  // SRAM init
  DEBUG_PRINTLN(F("Start SRAM"));
  sram_init(SRAM_CS_PIN); // Will set pin mode and such
  delay(1);

  bool restoredSram = false;

  // Try and restore from previous if we're not forced to not
  if (CLEAN_START == 0 && sram_get_populated()) {
    delay(1);

    // Restore the reading indexes and accumulator
    sram_read(&weatherReadingWriteIndex, SRAM_ADDR_READINGS_WRITE_INDEX, SRAM_SIZE_READINGS_WRITE_INDEX);
    sram_read(&weatherReadingReadIndex, SRAM_ADDR_READINGS_READ_INDEX, SRAM_SIZE_READINGS_READ_INDEX);
    sram_read_accumulator(&sampleAccumulator);

    if (
        weatherReadingWriteIndex > SRAM_MAX_READINGS ||
        weatherReadingReadIndex > SRAM_MAX_READINGS ||
        sampleAccumulator.timestamp == 0) {
      DEBUG_PRINTLN(F("ERROR: Sram Corrupted"));
    } else {
      DEBUG_PRINTLN(F("Ok! Restored from SRAM."));
      restoredSram = true;
    }
  }

  //  If we didn't restore it
  if (!restoredSram) {
    if (CLEAN_START) {
      DEBUG_PRINTLN(F("No SRAM, CLEAN_START"));
    } else {
      DEBUG_PRINTLN(F("ERROR: No state in SRAM."));
    }
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
void loop() {
  delay(1);
  wdt_reset();

  handle_esp();

  // Time to sample
  if (millis()-lastSampleMillis > SAMPLE_INTERVAL) {
    take_sample();
  }

  // If we've enough samples to make a reading
  if (sampleAccumulator.numSamples >= SAMPLES_PER_READING) {
    // Average the accumuator as a reading and store it
    WeatherReading currentReading = get_averaged_accumulator(sampleAccumulator);
    sram_write_reading(&currentReading, weatherReadingWriteIndex);

    // Need to have a test here that it wrote successfully, maybe reading and comaring or something?

    // Then zero the accumulator and store it
    zeroWeatherReading(&sampleAccumulator);
    sram_write_accumulator(&sampleAccumulator);

    #if DEBUG
    Serial.println();
    Serial.print(("--(WEATHER READING ("));
    Serial.print(weatherReadingWriteIndex);
    Serial.println("))--");
    printWeatherReading(currentReading);
    Serial.println();
    #endif

    // Update the index and save it to sram
    weatherReadingWriteIndex++;

    if (weatherReadingWriteIndex >= SRAM_MAX_READINGS) {
      weatherReadingWriteIndex = 0;
    }

    sram_write(weatherReadingWriteIndex, SRAM_ADDR_READINGS_WRITE_INDEX, SRAM_SIZE_READINGS_WRITE_INDEX);

    if (submitCountdown > 0) {
      submitCountdown--;
    }

    Serial.print("Till submit: ");
    Serial.println(submitCountdown);
  }
}

uint32_t get_unixtime() {
  return RTC.now().unixtime();
}

bool advance_read_pointer() {
  if (weatherReadingReadIndex == weatherReadingWriteIndex) {
    return false;
  }

  weatherReadingReadIndex++;

  if (weatherReadingReadIndex >= SRAM_MAX_READINGS) {
    weatherReadingReadIndex = 0;
  }

  // Store it
  sram_write(weatherReadingReadIndex, SRAM_ADDR_READINGS_READ_INDEX, SRAM_SIZE_READINGS_READ_INDEX);

  return true;
}

String generate_request_url(WeatherReading weatherReading) {
	// Make the url
	String outputUrl = "/report.php?";

	if (bmeConnected) {
	  if (!isnan(weatherReading.temperature)) {
	    outputUrl += "temp=";
	    outputUrl += weatherReading.temperature;
	  }

	  if (!isnan(weatherReading.humidity)) {
	      outputUrl += "&hum=";
	      outputUrl += weatherReading.humidity;

	      // If we have temperature and humidity then calculate and submit the heat index also
	      if (!isnan(weatherReading.temperature)) {
	        outputUrl += "&hI=";
	        outputUrl += computeHeatIndex(weatherReading.temperature, weatherReading.humidity, false);
	      }
	  }

	  if (!isnan(weatherReading.pressure)) {
	    outputUrl += "&pres=";
	    outputUrl += weatherReading.pressure;
	  }
	}

  outputUrl += "&bat=";
  outputUrl += weatherReading.batteryMv;
  outputUrl += "&wGust=";
  outputUrl += weatherReading.windGust;
  outputUrl += "&wSpd=";
  outputUrl += weatherReading.windSpeed;
  outputUrl += "&wDir=";
  outputUrl += weatherReading.windDirection;
	outputUrl += "&rain=";
	outputUrl += weatherReading.rain;
  outputUrl += "&lux=";
  outputUrl += weatherReading.lux;
  outputUrl += "&time=";
  outputUrl += weatherReading.timestamp;

  // Debug parameters
  outputUrl += "&rTime=";
  outputUrl += get_unixtime();
  outputUrl += "&attempt=";
  outputUrl += failedSubmits;
  outputUrl += "&fail=";
  outputUrl += requestFailReason;

	return outputUrl;
}


void submit_reading() {
  wdt_reset();

  DEBUG_PRINTLN();
  DEBUG_PRINT(F("Submitting Reading: "));
  DEBUG_PRINTLN(weatherReadingReadIndex);

  WeatherReading currentReading;

  for (int i=0; i<3; i++) {
    sram_read_reading(&currentReading, weatherReadingReadIndex);

    //printWeatherReading(currentReading);

    // Maybe have this count and keep skip it if the read fails a few times?
    //possibly a crc or something?
    if (currentReading.timestamp == 0 || currentReading.timestamp > get_unixtime()) {
      DEBUG_PRINT(F("Corrupt reading: "));

      if (i < SRAM_MAX_READ_ATTEMPTS) {
        DEBUG_PRINTLN("Retry");
        continue;
      }

      // Need to have this make the ESP send something like a
      // debug message saying the reading was skipped and sending the data
      // of the reading

      DEBUG_PRINTLN(F("Skipping"));

      // If this returns false we've submitted everything
      if (!advance_read_pointer()) {
        esp_sleep();
      }

      // When we return here the esp will still be in ESP_STATE_IDLE
      // And submit the next on the next loop
      return;
    }

    // No errors then break
    break;
  }

  String outputUrl = generate_request_url(currentReading);

  espState = ESP_STATE_AWAITING_RESULT;
  espRequestTime = get_unixtime();

  send_esp_serial(ESP_MSG_REQUEST, outputUrl.c_str());
}

float readADCVoltage(int channel=0, float ratio=1.0, int offset=0) {
  wdt_reset();

	// Get the vcc mV
	//////////////////////////////
	int referencePinMv = 2465; // Instead of 2500 as measured

	mcp.digitalWrite(MCP_REFV_ENABLE_PIN, LOW);
	delay(50); // For refV to stabilize

	float refPinReading = readADC(REF_ADC_PIN);

	mcp.digitalWrite(MCP_REFV_ENABLE_PIN, HIGH);

	// Get the channel mV
	//////////////////////////////
	float channelPinReading = readADC(channel);

  float vccMv = (1023.0 / refPinReading) * referencePinMv;
  float pinMv = (vccMv / 1023.0) * channelPinReading;
	float readingMv = pinMv * ratio;

  DEBUG2_PRINT(F("ADC channel: "));
  DEBUG2_PRINT(channel);
  DEBUG2_PRINT(F(" refPin: "));
  DEBUG2_PRINT(refPinReading);
  DEBUG2_PRINT(F(" vccMv: "));
	DEBUG2_PRINT(vccMv);

  DEBUG2_PRINT(F(" channelPin: "));
  DEBUG2_PRINT(channelPinReading);
	DEBUG2_PRINT(F(" pinMv: "));
	DEBUG2_PRINT(pinMv);
  DEBUG2_PRINT(F(" readingMv: "));
  DEBUG2_PRINT(readingMv);
	DEBUG2_PRINT(F(" resultMv: "));
	DEBUG2_PRINTLN(readingMv+offset);

  return readingMv + offset;
}

void send_esp_serial(char messageType, const char *value) {
  wdt_reset();

  DEBUG_PRINT(F("(ATMega->ESP)"));
  DEBUG_PRINT((int)messageType);
  DEBUG_PRINT((int)strlen(value));
  DEBUG_PRINT(value);

  ESPSerial.write(messageType);
  ESPSerial.write((char)strlen(value));
  ESPSerial.write(value);

  DEBUG_PRINTLN(" (done)");
}

void handle_esp_serial() {
  Serial.println("ESP RECV: ");
  Serial.print(ESPRecvBuffer);

  ESPRecvIndex = 0;
}

void recv_esp_serial() {
	// Print ESP serial messages
	if (!ESPSerial.available()) {
    return;
  }

	uint8_t rxByte = ESPSerial.read();

  // Newline or end of the buffer
  if (rxByte == 10 || ESPRecvIndex == ESP_RECV_BUFFER_SIZE-1) {
    ESPRecvBuffer[ESPRecvIndex++] = '\0';
    handle_esp_serial();
  } else {
    ESPRecvBuffer[ESPRecvIndex++] = rxByte;
  }

	// 	if (ESPNewline) {
	// 		ESPNewline = false;
  //
	// 		// if (!ESPReplyBuffering) {
	// 		// 	DEBUG_PRINT(F("ESP (recv)"));
	// 		// }
	// 	}
  //
	// 	// // Print it if it's not a reply to us (Just it trying to print something)
	// 	// if (!ESPReplyBuffering && rxByte) {
	// 	// 	Serial.print((char)rxByte);
	// 	// }
  //
	// 	if (rxByte == 126) {
	// 		ESPReplyBufferIndex = 0;
	// 		ESPReplyBuffering = true;
	// 	} else if (rxByte == 10) {
	// 		ESPNewline = true;
	// 		ESPReplyBuffering = false;
	// 	}
  //
	// 	if (ESPReplyBuffering && ESPReplyBufferIndex < 5) {
	// 		ESPReplyBuffer[ESPReplyBufferIndex++] = rxByte;
	// 	}
	// }
}

void read_anemometer() {
  // No wind
  if (anemometerPulses == 0) {
    // DEBUG_PRINTLN(F("Avg Wind Tdelta: 0"));
    // DEBUG_PRINTLN(F("Wind MPH: 0"));
    return;
  }

  cli();
  // Get the average Tdelta for the anemometer since our last sample
  float averagePulseTDelta = anemometerTDeltaAccumulator / float(anemometerPulses);
  anemometerPulses = 0;
  anemometerTDeltaAccumulator = 0;
  sei();

  // DEBUG_PRINT(F("Avg Wind Tdelta: "));
  // DEBUG_PRINTLN(averagePulseTDelta);

  float anemometerMph = ANEMOMETER_TDELTA_1_MPH / averagePulseTDelta;

  // DEBUG_PRINT(F("Wind MPH: "));
  // DEBUG_PRINTLN(anemometerMph);

  sampleAccumulator.windSpeed += int32_t(anemometerMph*100);

  // DEBUG_PRINT(F("Wind Accumulator: "));
  // DEBUG_PRINTLN(sampleAccumulator.windSpeed);
  // DEBUG_PRINT(F("AccumAvg: "));
  // DEBUG_PRINTLN(float(sampleAccumulator.windSpeed/sampleAccumulator.numSamples)*.01);
}

void read_anemometer_gust() {
  // No wind
  if (anemometerMinTDelta == ULONG_MAX) {
    return;
  }

  cli();
  float anemometerGustMph = ANEMOMETER_TDELTA_1_MPH / anemometerMinTDelta;
  anemometerMinTDelta = ULONG_MAX;
  sei();

  // DEBUG_PRINT(F("Sample Gust MPH: "));
  // DEBUG_PRINTLN(anemometerGustMph);

  int32_t gustInt32 = int32_t(anemometerGustMph*100);

  if (gustInt32 > sampleAccumulator.windGust) {
    sampleAccumulator.windGust = gustInt32;

    // DEBUG_PRINT(F("NEW GUST RECORD: "));
    // DEBUG_PRINTLN(anemometerGustMph);
  }
}
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

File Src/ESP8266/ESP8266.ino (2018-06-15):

#include <ESP8266WiFi.h>
#include "SoftwareSerial.h"
#include <ESP8266WebServer.h>
//#include "SPISlave.h"
#include <Wire.h>
#define I2CAddressESPWifi 8

#include "config.h"
#include "helpers.h"

#define SUCCESS_PIN D1
#define RESULT_PIN D2

#define ATMEGA_RX_PIN D5
#define ATMEGA_TX_PIN D6

SoftwareSerial ATmegaSerial(ATMEGA_RX_PIN, ATMEGA_TX_PIN);

#define ATMEGA_BUFFER_SIZE 300
char ATmegaSerialBuffer[ATMEGA_BUFFER_SIZE];
int ATmegaSerialIndex = 0;

#define STATE_WAIT 0
#define STATE_CMD_RCVD 1
#define STATE_RECIEVING 3
#define STATE_FINISHED 4

#define REQUEST_TIMEOUT_MS 45000
#define CONNECT_TIMEOUT_MS 30000
#define WIFI_CLIENT_TIMEOUT_MS 30000

int ATmegaSerialState = STATE_WAIT;
char ATmegaSerialCommand = 0;
char ATmegaSerialLength = 0;

#define DEBUG_PIN D7
bool debugMode = false;
//
// void on_spi_data(uint8_t *data, size_t len) {
//   String message = String((char *)data);
//
//   if(message.equals("Hello Slave!")) {
//       SPISlave.setData("Hello Master!");
//   } else if(message.equals("Are you alive?")) {
//       char answer[33];
//       sprintf(answer,"Alive for %u seconds!", millis() / 1000);
//       SPISlave.setData(answer);
//   } else {
//       SPISlave.setData("Say what?");
//   }
//   Serial.printf("Question: %s\n", (char *)data);
// }
//
// void on_spi_data_sent() {
//   Serial.println("Answer Sent");
// }
//
// void on_status(uint32_t data) {
//   Serial.printf("Status: %u\n", data);
//   SPISlave.setStatus(millis()); //set next status
// }
//
// void on_status_sent() {
//   Serial.println("Status Sent");
// }
//
// void setup_spi_slave() {
//   SPISlave.onData(on_spi_data);
//   SPISlave.onDataSent(on_spi_data_sent);
//   SPISlave.onStatus(on_status);
//   SPISlave.onStatusSent(on_status_sent);
//   SPISlave.begin();
//
//   // Set the status register (if the master reads it, it will read this value)
//   SPISlave.setStatus(millis());
//
//   // Sets the data registers. Limited to 32 bytes at a time.
//   // SPISlave.setData(uint8_t * data, size_t len); is also available with the same limitation
//   SPISlave.setData("Ask me a question!");
// }

struct NetworkInfo {
  char ssid[100];
  int rssi;
  bool open;
};

unsigned short numDetectedNetworks = 0;
NetworkInfo *detectedNetworks;
const char *hostedSSID = "WeatherStation_AP";
IPAddress apIP(192, 168, 1, 1);
ESP8266WebServer server(80);

void scan_networks() {
  // Set WiFi to station mode and disconnect from an AP if it was previously connected
  WiFi.mode(WIFI_STA);
  WiFi.disconnect();
  delay(100);

  if (numDetectedNetworks) {
    free(detectedNetworks);
  }

  // WiFi.scanNetworks will return the number of networks found
  numDetectedNetworks = WiFi.scanNetworks();
  Serial.println("scan done");


  Serial.print(numDetectedNetworks);
  Serial.println(" networks found");

  if (numDetectedNetworks) {
      detectedNetworks = (NetworkInfo*)malloc(sizeof(NetworkInfo)*numDetectedNetworks);

      for (int i = 0; i < numDetectedNetworks; ++i) {
        strcpy(detectedNetworks[i].ssid, WiFi.SSID(i).c_str());
        detectedNetworks[i].rssi = WiFi.RSSI(i);
        detectedNetworks[i].open = (WiFi.encryptionType(i) == ENC_TYPE_NONE);

        Serial.print(detectedNetworks[i].ssid);
        Serial.print(" ");
        Serial.print(detectedNetworks[i].rssi);
        Serial.print("dB [");
        Serial.print(detectedNetworks[i].open?"open":"enc");
        Serial.println("]");
      }
  }

  Serial.println("");
}

void handleRoot() {
  String response;

  response += "<h1>Detected Networks</h1>";

  for (int i=0; i<numDetectedNetworks; i++) {
    response += i;
    response += ". ";
    response += detectedNetworks[i].ssid;
    response += ": (";
    response += detectedNetworks[i].rssi;
    response += ")";
    response += (detectedNetworks[i].open?" ":"*");
    response += "<br>";
  }

	server.send(200, "text/html", response.c_str());
}

void setup()
{
  Serial.begin(19200);
  Serial.setDebugOutput(true);

  // Debug functions
  pinMode(DEBUG_PIN, INPUT);
  debugMode = digitalRead(DEBUG_PIN);

  Serial.println(".......");
  Serial.print("Initilizing ESP8266...........");
  Serial.print("Finished: ");
  Serial.println(debugMode?"Debug Mode":"Slave Mode");

  if (debugMode) {
    // Set WiFi to station mode and disconnect from an AP if it was previously connected
    scan_networks();
    WiFi.disconnect();
    WiFi.mode(WIFI_AP);
    delay(100);

    // Then setup as an ap
    WiFi.softAPConfig(apIP, apIP, IPAddress(255, 255, 255, 0));
    WiFi.softAP(hostedSSID);
    Serial.println(WiFi.softAPIP());

    server.on("/", handleRoot);
    server.begin();

    Serial.println("Debug Server Started");
  } else {
    ATmegaSerial.begin(ESP_ATMEGA_BAUD_RATE);
    // We print this to make the serial sync before the commands are sent
    ATmegaSerial.println("......................");

    //WiFi.setAutoConnect(false);
    //connect_to_wifi();
  	// WiFi.persistent(false);

    //setup_spi_slave();
    //
    // Wire.begin(0, 2); //SDA, SCL, D3, D4//Change to Wire.begin() for non ESP.
  }

  pinMode(RESULT_PIN, OUTPUT);
  pinMode(SUCCESS_PIN, OUTPUT);

  digitalWrite(RESULT_PIN, LOW);
  digitalWrite(SUCCESS_PIN, LOW);

  Serial.println("Done init");
}
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

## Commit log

2017-09-24 Added Parts List Spreadsheet
    [PartsList.ods]
2017-09-27 Fixed datapoint selection algorithm cause it was terrible is smarter now. Added current info header and degree symbols instead of *
2017-10-20 Added led PWM; changed server ip
2017-10-24 added anemometer and changed digitalWrite to analogWrite for leds since they werent turning off
2017-12-12 Removed heatIndex.h put functions in helpers.h
2017-12-12 Added header for mcp23008 8 bit IO expander. Library is modified to support interrupts.
2017-12-12 Added anemometer calibration data
    [AnemometerCalibration.ods]
2017-12-12 For BOM and pricing
    [PartsList.ods]
2017-12-15 Made the interrupt function use ICACHE_RAM_ATTR for quicker execution to help avoid crashes
2017-12-15 Anemometer refactoring, made the station submit in mph instead of rpm by using stored calibration data.
2017-12-15 Battery reading refactoring and made more accurate
2017-12-15 Removed old for DHT sensor
2017-12-22 Added printWeatherReading function in helpers and made default values for a reading to zero for ease of averaging readings.
2017-12-26 Added more reference material
2017-12-26 rename of sample reading
2017-12-26 LED control changes
2017-12-27 Added beginnings of calibration mode
2017-12-27 Made it used a sampleAccumulator reading instead of one for each sample to save on ram
2017-12-27 Need this for the sampleAccumulator
2017-12-27 Added bosh bme driver code
2017-12-28 Moved battery block to the top of the sensing
2017-12-28 Added revised schematic
2017-12-28 I think I finally am doing the battery voltage measurement more or less correct.
2017-12-29 Added beginnings of battery percent approximation
2017-12-29 Should have been in the last commit with battery percent approximation
2017-12-29 Clarifying the text in some print()s
2018-01-13 Schematic and Reference update
    [PowerPerfboard.kicad_pcb, PowerPerfboard.sch, PowerStripboard.kicad_pcb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]
2018-01-18 Working attiny sample prototype
2018-01-27 Adding SRAM chip support to retain data across crashes
    [ESP8266.ino, MCP_23A1024.h]
2018-01-27 Print numSamples and numBatterySamples in printWeatherReading
2018-01-31 Added uptime printout
2018-01-31 Added pretty print timestamp function
2018-01-31 Rearranged schematic files
    [PowerPerfboard.kicad_pcb, PowerPerfboard.sch, PowerStripboard.kicad_pcb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]
2018-02-01 Added Indicator LEDS again and more informative pin map
2018-02-01 Made SRAM storage, retrieval work correctly.
    [ATmega328p.ino, MCP_23A1024.h, weather_readings.h]
2018-02-02 Made battery samples work correctly and solar panel enable/disable
    [ATmega328p.ino, MCP_23A1024.h]
2018-02-02 Didn't need this? Need to fix on a time reference
    [weather_readings.h]
2018-02-04 Working (I think) again complete station, hopefully no more crashes
    [ATmega328p.ino, ESP8266.ino, MCP_23A1024.h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]
2018-02-05 More cleaning and starting new docs
    [PowerPerfboard.kicad_pcb, PowerPerfboard.sch, PowerStripboard.kicad_pcb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]
2018-02-15 Added BH1750 Lux Sensor
2018-02-15 Debug print levels added
2018-02-15 SRAM layout rearrangements *take use sizeof for the storage of readings and the accumulator *longer populated key *Easy to adjust spi HZ
2018-02-15 ESP debug request support, print and send reset flags to server on restart so we can track and hopefully reduce resets
    [ATmega328p.ino]
2018-02-20 Bug with esp print, would print u_int8 instead of as char
    [ATmega328p.ino]
2018-02-23 Changed types for readings lots of uint64 to uint32 cause 64 was way too big pointless waste. Other type changes like double to float
    [ATmega328p.ino, MCP_23A1024.h, weather_readings.h]
2018-02-23 Added ram usage debug printout
2018-02-23 Changed a bunch of prints to shorten and reduce messages to save on ram or flash
    [ATmega328p.ino]
2018-02-23 Forgot this in the batteryMv change commit
2018-03-05 Swapped esp serial and request result pins because the new result pins are low on reboot so if the esp crashes then the atmega wont think the esp had a result
    [ESP8266.ino]
2018-03-05 Added esp RESETTING mode
    [ATmega328p.ino]
2018-03-20 Made RTC and BME use I2C library instead of Wire, also deleted some unused things so it could still fit in flash
2018-03-20 Made IO expander print the result of the fetch
2018-03-20 Beginnings of error checking for readings
    [weather_readings.h]
2018-03-20 Added I2C bus reset on ATMega reboot as per spec
    [ATmega328p.ino]
2018-04-16 Updated Schematic
    [WeatherStation.kicad_pcb, WeatherStation.sch]
2018-05-14 Changed ESP reset pin to a different pin
2018-05-14 Beginnings of lux sensor disabling on error like bme can
    [ATmega328p.ino]
2018-05-14 Made I2C lib print user friendly device name from address on bus errors
    [I2C.cpp]
2018-05-14 Schematic Updates
    [PowerPerfboard.kicad_pcb, PowerPerfboard.sch, PowerStripboard.kicad_pcb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]
2018-05-17 Changed pin assignments to reflect the new
2018-05-17 I2C error handling improvements. Displays Read/Write, # of errors. Resets the i2c bus after 2 errors on it
    [BH1750.cpp, BME280.cpp, I2C.cpp]
2018-05-17 Added version and compile time print on station boot
2018-05-17 Longer time for refV to stabilize
    [ATmega328p.ino]
2018-05-17 Change esp reset pin to one on mcp23008
2018-05-17 I2C reboot code refresh
    [ATmega328p.ino]
2018-05-17 Set reference pin on atmega to be vcc with cap on external pin
2018-05-20 ADC Overhaul for battery v and other readings
2018-05-20 Moved battery reading higher up the sample function to before wind reading
2018-06-02 C : : Updated Schemati
    [WeatherStation.kicad_pcb, WeatherStation.sch]
2018-06-28 Added back request fail reason submission
    [ATmega328p.ino]
2025-11-19 Add Conditional Automation Engine for PLC-like control
    Implements rule-based automation system for greenhouse control:
    - automation_rules.h: Data structures for rules stored in EEPROM
    - automation_engine.h: Rule evaluation with hysteresis and cooldowns
    - Integrates into ATmega328p.ino main firmware
    Features:
    - Support for 8 rules with 2 conditions each
    - 12 sensor types including derived values (heat index, dew point)
    - Actions: relay control, PWM, alerts
    - Hysteresis to prevent rapid cycling
    - Cooldown timers for rate limiting
    [ATmega328p.ino, automation_engine.h, automation_rules.h]

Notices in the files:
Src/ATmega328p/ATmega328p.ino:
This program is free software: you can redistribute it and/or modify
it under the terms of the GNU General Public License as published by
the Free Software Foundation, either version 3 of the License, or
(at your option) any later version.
